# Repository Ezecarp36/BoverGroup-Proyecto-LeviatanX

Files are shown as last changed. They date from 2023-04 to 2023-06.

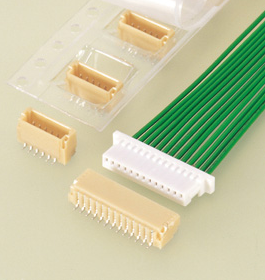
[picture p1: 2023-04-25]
Libreriaskicad(2023)/3d/3d/jst-sh-smd-connectors-1.snapshot.4/JST-SH-preview.png

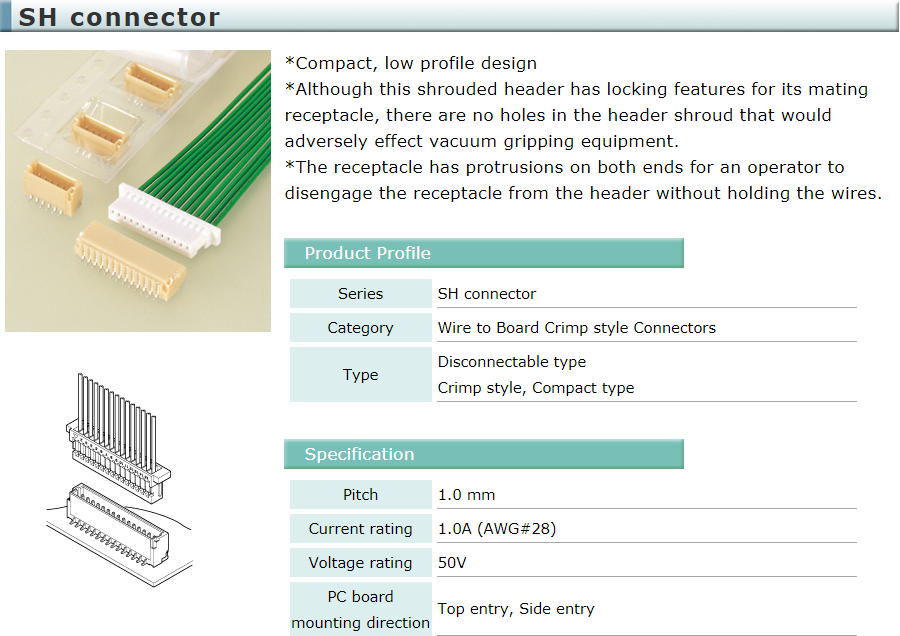
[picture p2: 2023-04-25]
Libreriaskicad(2023)/3d/3d/jst-sh-smd-connectors-1.snapshot.4/JST-SH.png

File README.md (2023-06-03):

# BoverGroup-Proyecto-LeviatanX
El Bover Group, compuesto por tres estudiantes de Septimo año de la E.E.S.T.Nº5 "2 DE ABRIL", se encuentra desarrollando un emocionante proyecto "LeviatanX" se trata en principio de un proyecto de varias etapas la primera es la realizacion de un drone controlado por radiocontrol para su uso en monitoreo y vigilancia. El proyecto será presentado en la materia Proyectos Electrónicos, dirigida por el Ing. Martin Leguizamón. Los integrantes del grupo son Leandro Benitez, Ezequiel Sierra y Gabriel Romero, quienes trabajan juntos para en un futuro automatizar el drone, permitiéndole volar de manera autónoma y a esto agregar la utilizacion de una cámara para reconocimiento con machine learning en tareas de monitoreo y vigilancia. Este proyecto tiene como objetivo ser un gran avance en la tecnología de drones, demostrando su creatividad y trabajo en equipo.
Tenemos un drive el cual plasmamos la informacion de los componentes usados y la documentacion necesaria para llevar a cabo el proyecto:
Drive: https://drive.google.com/drive/folders/1-x7SCu_ywuLYVk6GRU4Gz9AUGYImAjfw?usp=drive_link

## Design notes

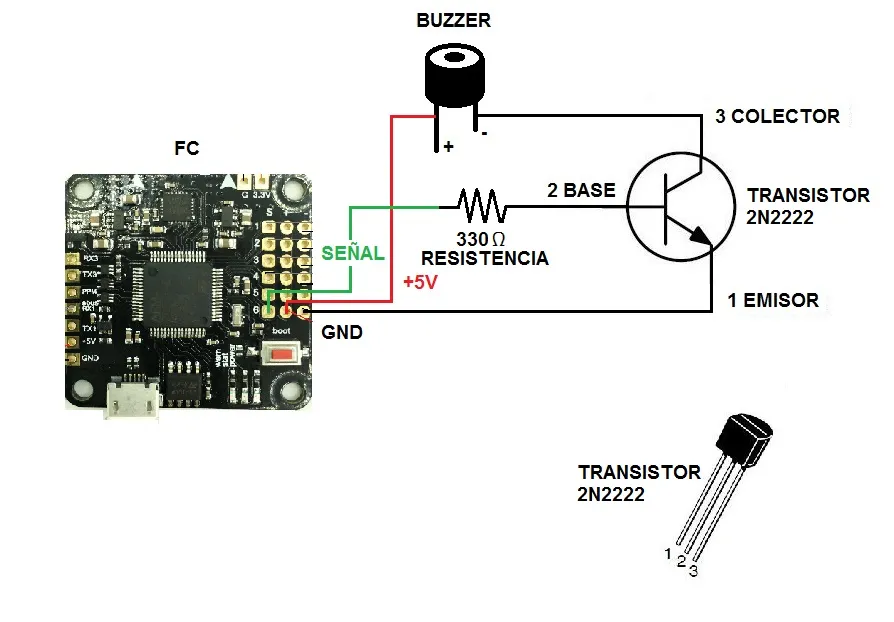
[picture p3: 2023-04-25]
Hardware/PCB-Controladora-Vuelo/Img/TransistorBuzzer.webp

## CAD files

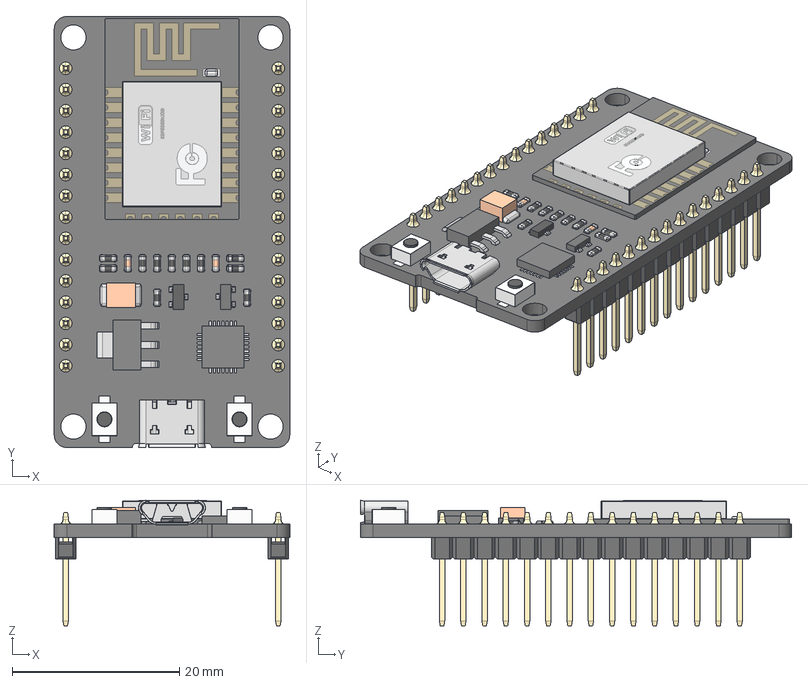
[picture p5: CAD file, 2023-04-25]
Libreriaskicad(2023)/3d/3d/esp32_dev_kit_v1_asm.stp
28.1 x 51.5 x 15.0 mm
PCB
PIN x 30
WIFI_CARD_2
RECTANGULARCHIP_2
MICROCHIP_2
TANCHIP_2
TRANSISTOR_3-LEG_2
RESISTOR1_2 x 11
RESISTOR2-32_2 x 2
TRANSISTOR_3-LEG2_2
BUTTONFLASH-13_2 x 2
BUTTONFLASH-14_2 x 2
USB_SOCKET_2

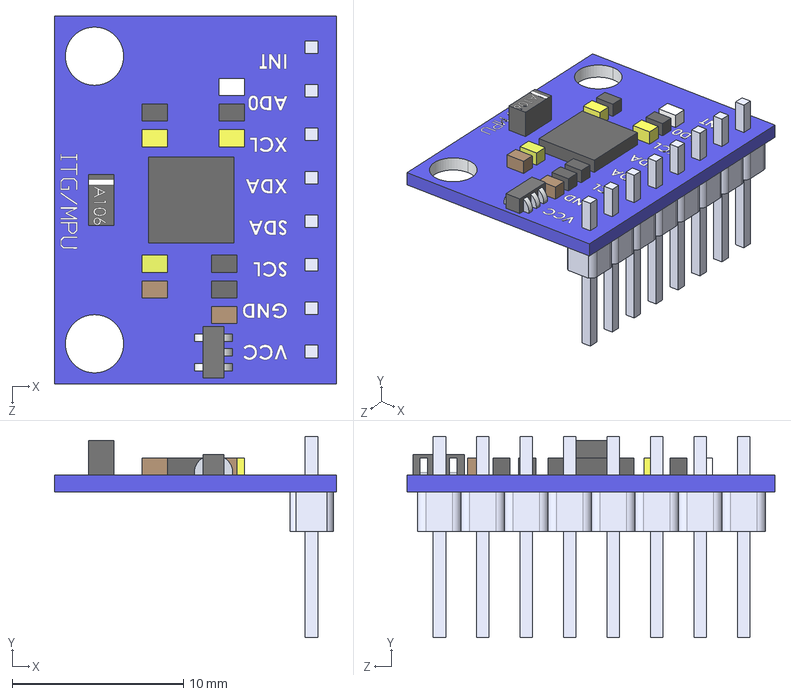
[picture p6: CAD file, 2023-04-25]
Libreriaskicad(2023)/3d/3d/ITG-MPU.STEP
16.5 x 11.8 x 21.5 mm
8 Header-Pin
Placa_Base

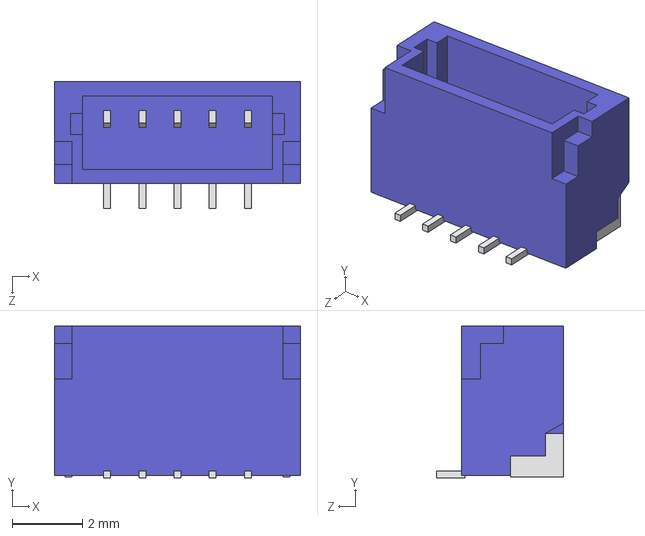
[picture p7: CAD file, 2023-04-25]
Libreriaskicad(2023)/3d/3d/jst-sh-smd-connectors-1.snapshot.4/BMxxB-SRSR-TB/BM05B-SRSS-TB.STEP
7.00 x 4.32 x 3.60 mm

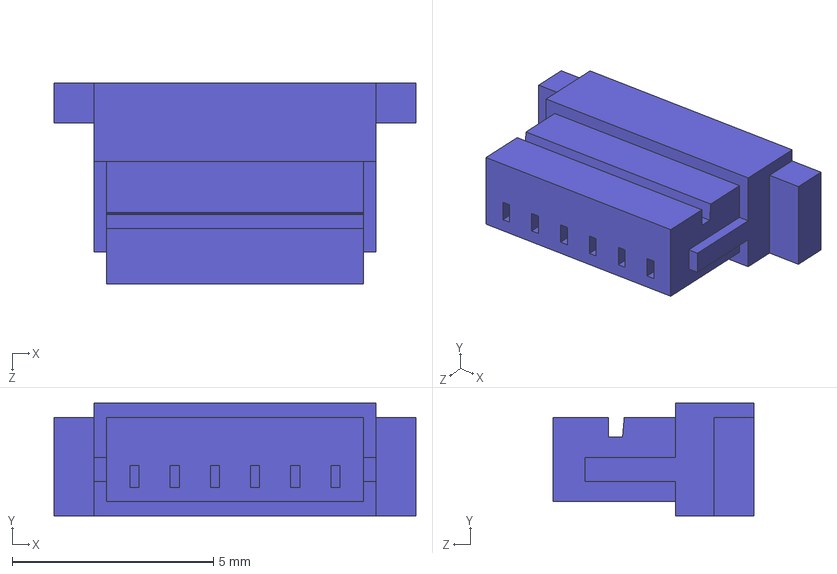
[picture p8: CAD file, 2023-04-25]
Libreriaskicad(2023)/3d/3d/jst-sh-smd-connectors-1.snapshot.4/SHR-xxV-S-B/SHR-06V-S-B.STEP
9.00 x 2.80 x 5.00 mm

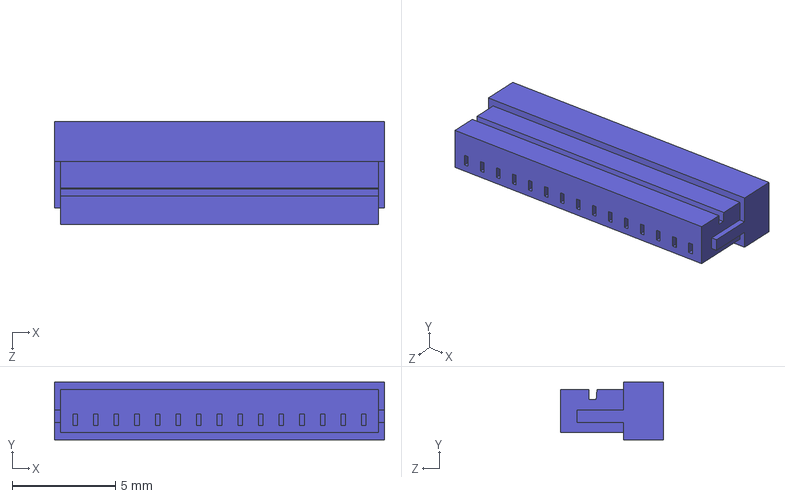
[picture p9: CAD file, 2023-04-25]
Libreriaskicad(2023)/3d/3d/jst-sh-smd-connectors-1.snapshot.4/SHR-xxV-S/SHR-15V-S.STEP
16.0 x 2.80 x 5.00 mm

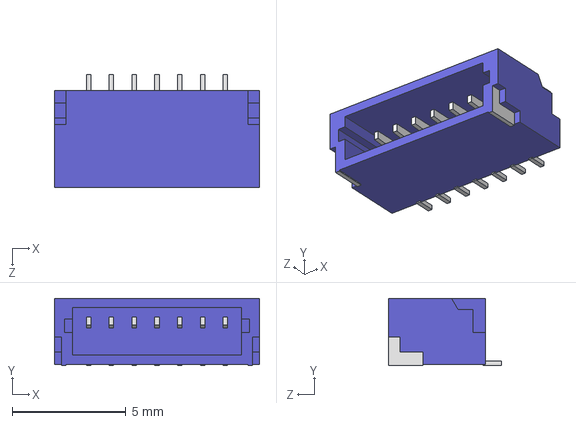
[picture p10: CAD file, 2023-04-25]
Libreriaskicad(2023)/3d/3d/jst-sh-smd-connectors-1.snapshot.4/SMxxB-SRSS-TB/SM07B-SRSS-TB.STEP
9.00 x 2.96 x 4.95 mm

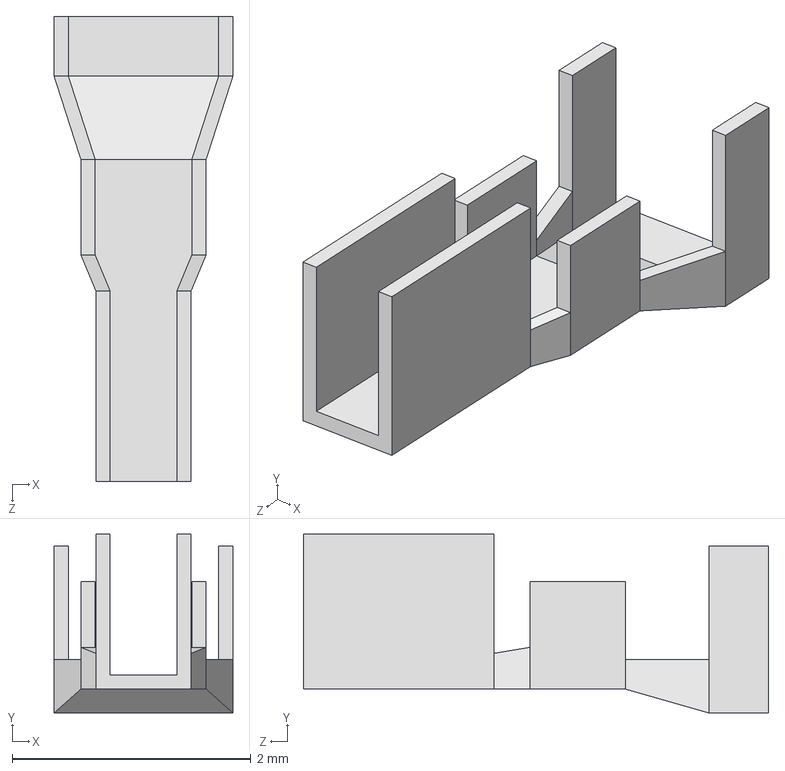
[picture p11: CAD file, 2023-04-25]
Libreriaskicad(2023)/3d/3d/jst-sh-smd-connectors-1.snapshot.4/SSH-003T-P0.2-H/SSH-003T-P0.2-H.STEP
1.50 x 1.50 x 3.90 mm

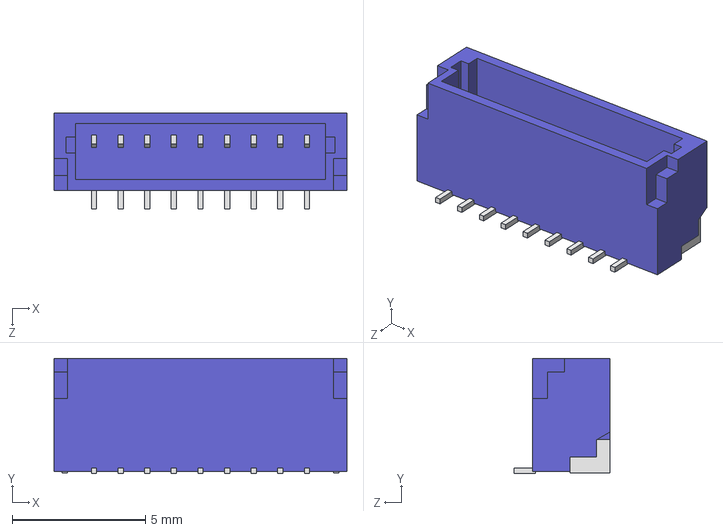
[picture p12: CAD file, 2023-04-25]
Libreriaskicad(2023)/3d/3d/jst-sh-smd-connectors-1.snapshot.4/BMxxB-SRSR-TB/BM09B-SRSS-TB.STEP
11.0 x 4.32 x 3.60 mm

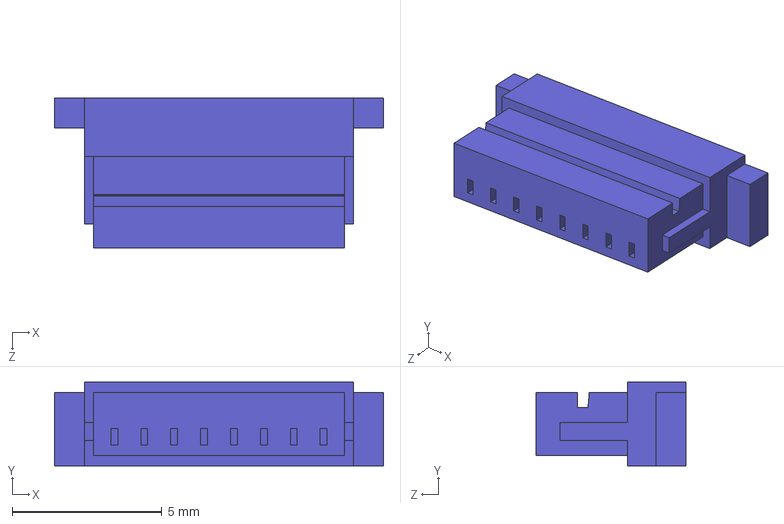
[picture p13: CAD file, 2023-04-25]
Libreriaskicad(2023)/3d/3d/jst-sh-smd-connectors-1.snapshot.4/SHR-xxV-S-B/SHR-08V-S-B.STEP
11.0 x 2.80 x 5.00 mm

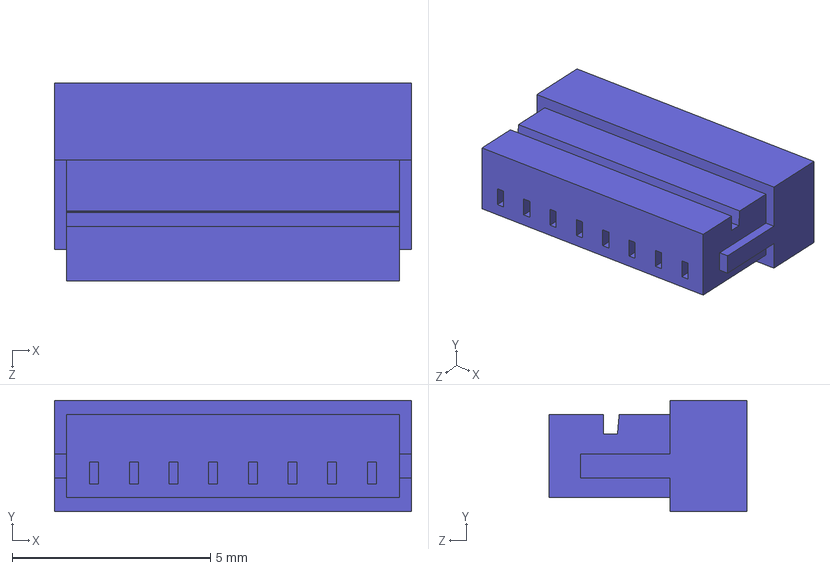
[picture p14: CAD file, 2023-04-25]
Libreriaskicad(2023)/3d/3d/jst-sh-smd-connectors-1.snapshot.4/SHR-xxV-S/SHR-08V-S.STEP
9.00 x 2.80 x 5.00 mm

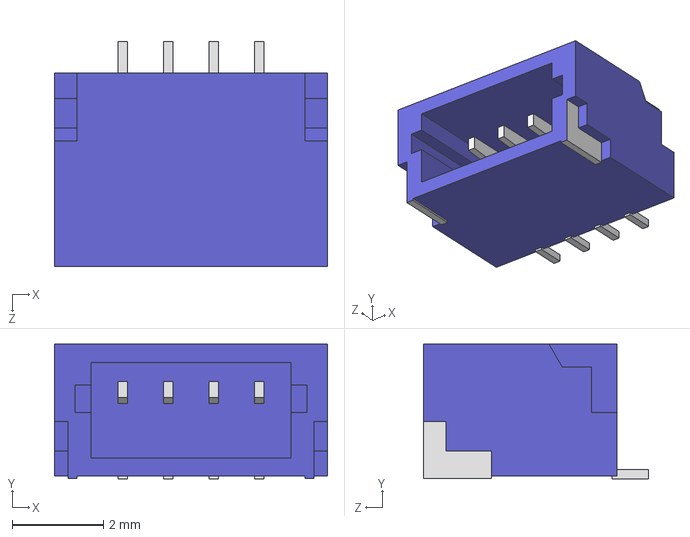
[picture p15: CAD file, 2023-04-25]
Libreriaskicad(2023)/3d/3d/jst-sh-smd-connectors-1.snapshot.4/SMxxB-SRSS-TB/SM04B-SRSS-TB.STEP
6.00 x 2.96 x 4.95 mm

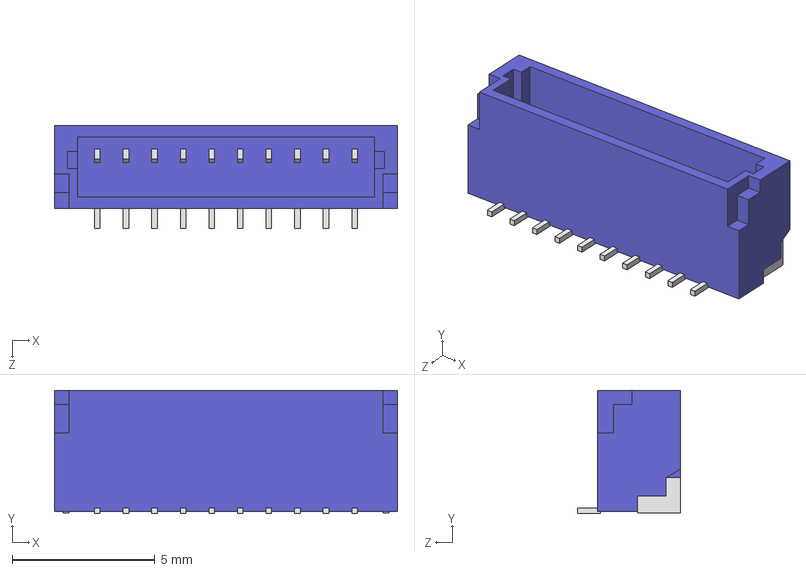
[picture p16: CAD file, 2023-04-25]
Libreriaskicad(2023)/3d/3d/jst-sh-smd-connectors-1.snapshot.4/BMxxB-SRSR-TB/BM10B-SRSS-TB.STEP
12.0 x 4.32 x 3.60 mm

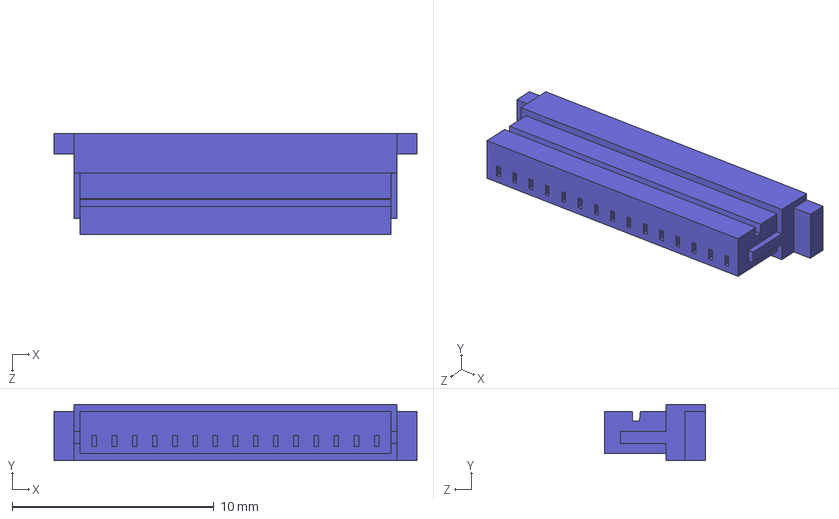
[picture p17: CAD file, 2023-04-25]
Libreriaskicad(2023)/3d/3d/jst-sh-smd-connectors-1.snapshot.4/SHR-xxV-S-B/SHR-15V-S-B.STEP
18.0 x 2.80 x 5.00 mm

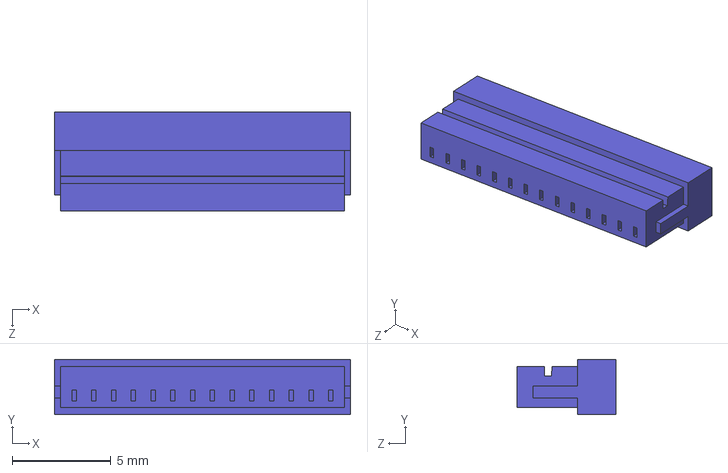
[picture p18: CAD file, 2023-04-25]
Libreriaskicad(2023)/3d/3d/jst-sh-smd-connectors-1.snapshot.4/SHR-xxV-S/SHR-14V-S.STEP
15.0 x 2.80 x 5.00 mm

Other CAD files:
Libreriaskicad(2023)/3d/3d/jst-sh-smd-connectors-1.snapshot.4/SMxxB-SRSS-TB/SM02B-SRSS-TB.STEP
Libreriaskicad(2023)/3d/3d/NRF24L01.step
Libreriaskicad(2023)/3d/3d/jst-sh-smd-connectors-1.snapshot.4/BMxxB-SRSR-TB/BM06B-SRSS-TB.STEP
Libreriaskicad(2023)/3d/3d/jst-sh-smd-connectors-1.snapshot.4/SHR-xxV-S-B/SHR-09V-S-B.STEP
Libreriaskicad(2023)/3d/3d/jst-sh-smd-connectors-1.snapshot.4/BMxxB-SRSR-TB/BM02B-SRSS-TB.STEP
Libreriaskicad(2023)/3d/3d/jst-sh-smd-connectors-1.snapshot.4/BMxxB-SRSR-TB/BM03B-SRSS-TB.STEP
Libreriaskicad(2023)/3d/3d/jst-sh-smd-connectors-1.snapshot.4/BMxxB-SRSR-TB/BM04B-SRSS-TB.STEP
Libreriaskicad(2023)/3d/3d/jst-sh-smd-connectors-1.snapshot.4/BMxxB-SRSR-TB/BM07B-SRSS-TB.STEP
Libreriaskicad(2023)/3d/3d/jst-sh-smd-connectors-1.snapshot.4/BMxxB-SRSR-TB/BM08B-SRSS-TB.STEP
Libreriaskicad(2023)/3d/3d/jst-sh-smd-connectors-1.snapshot.4/BMxxB-SRSR-TB/BM11B-SRSS-TB.STEP
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

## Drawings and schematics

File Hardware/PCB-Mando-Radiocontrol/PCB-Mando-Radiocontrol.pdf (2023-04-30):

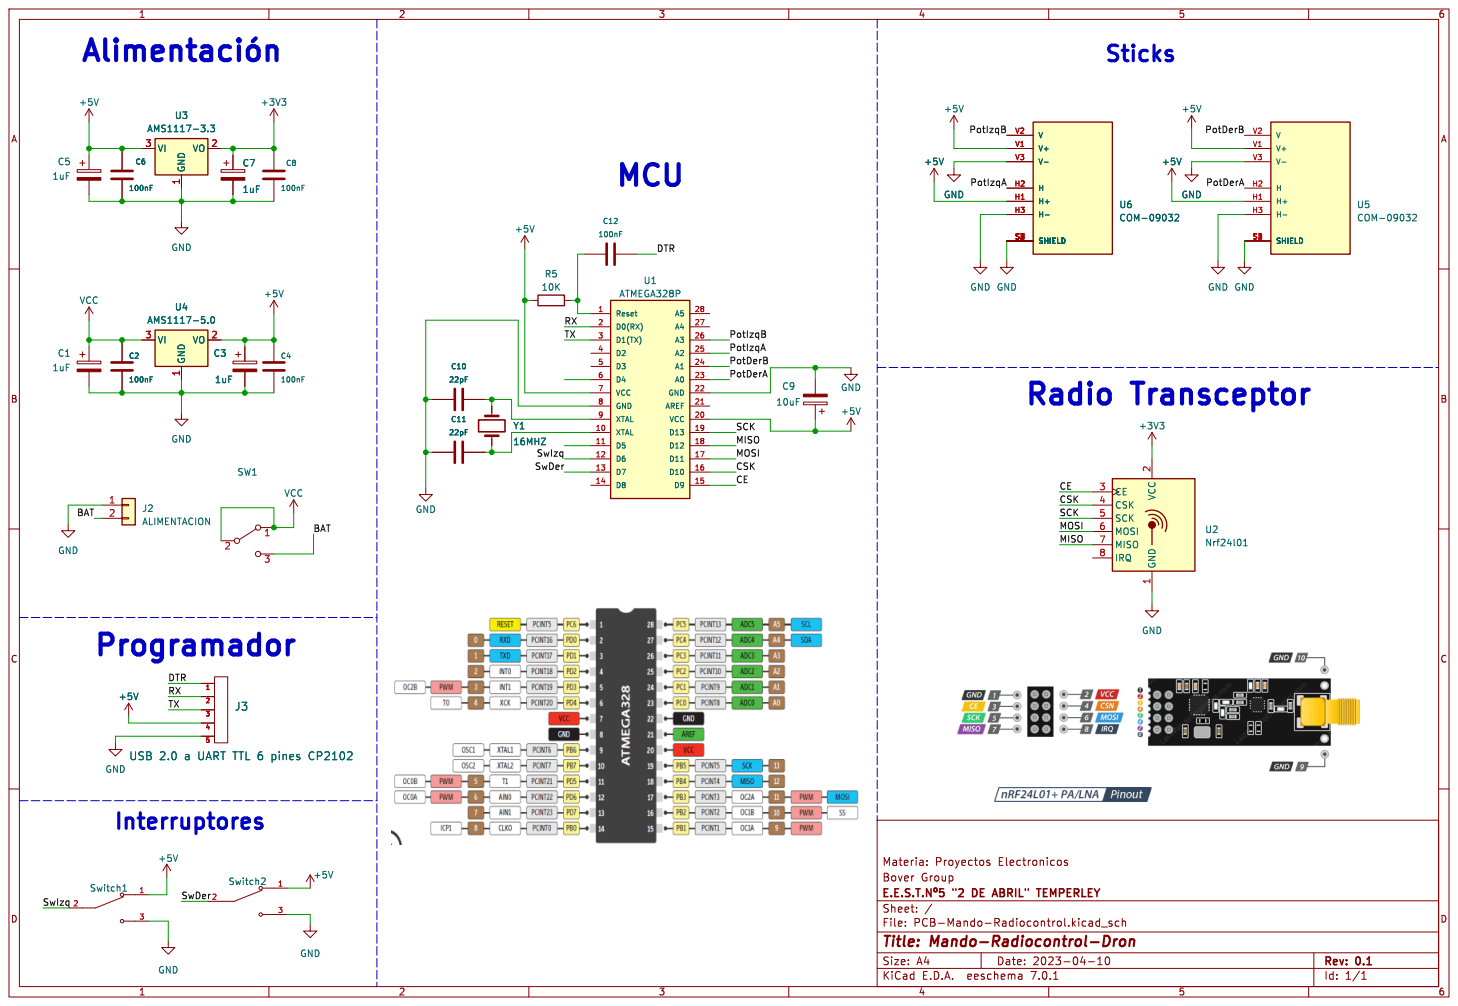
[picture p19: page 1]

1 VO 2 VI 3 U4 AMS1117-5.0 VCC GND

2 CE 3 CSK 4 SCK 5 MOSI 6 MISO 7

J3 USB 2.0 a UART TTL 6 pines CP2102

Id: 1/1 Title: Mando-Radiocontrol-Dron

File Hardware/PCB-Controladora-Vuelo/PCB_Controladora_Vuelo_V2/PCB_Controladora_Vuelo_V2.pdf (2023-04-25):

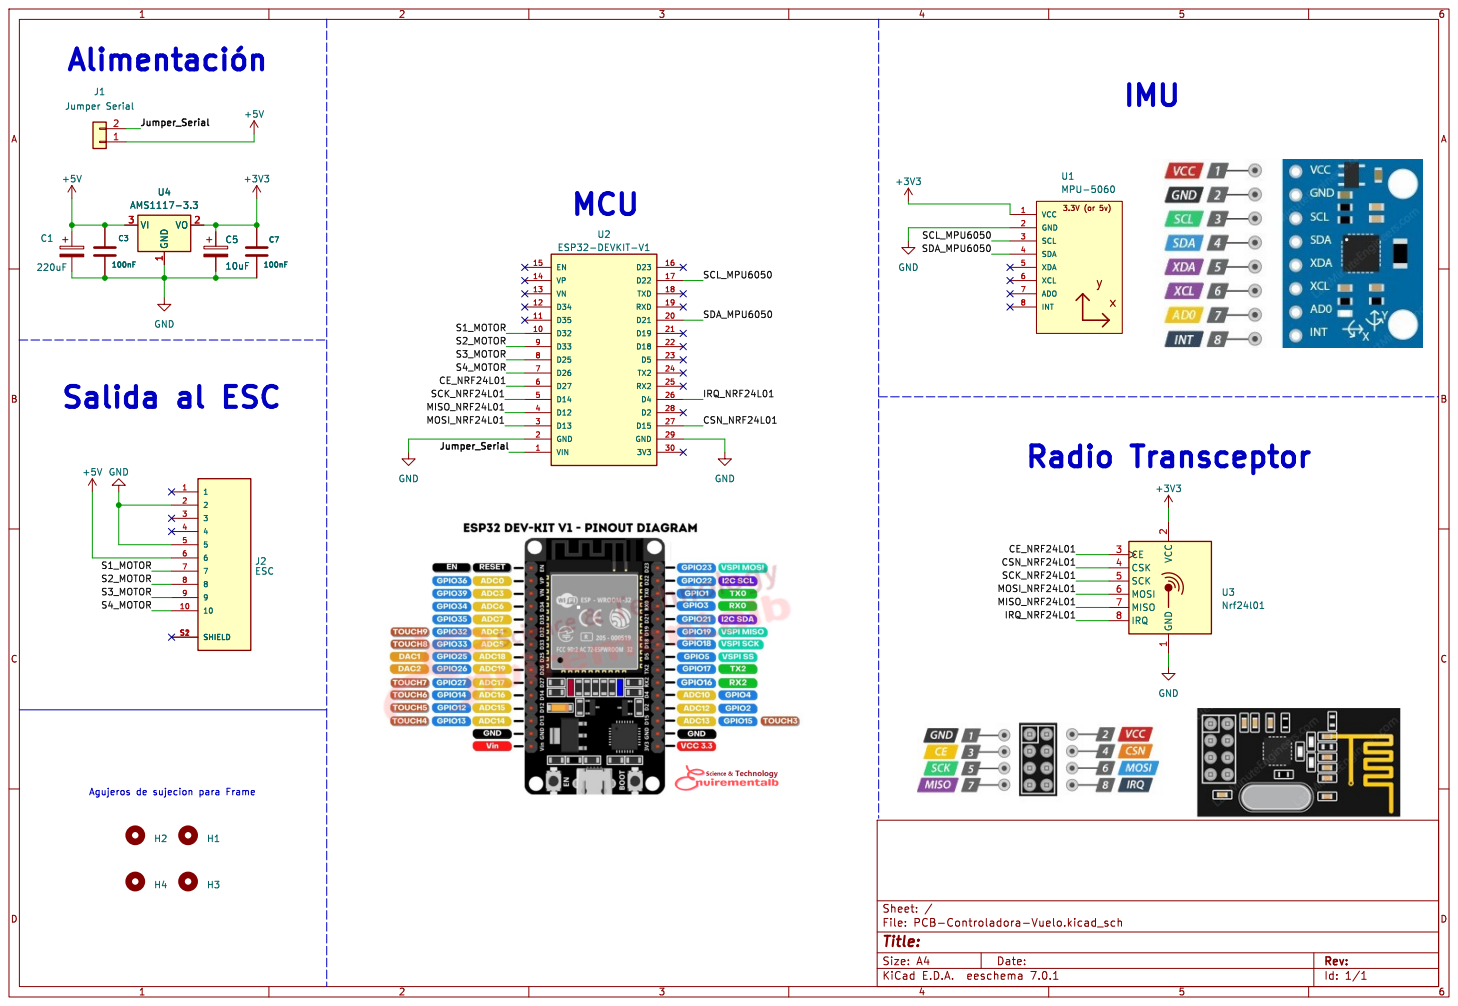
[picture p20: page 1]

1 VO 2 VI 3 U4 AMS1117-3.3 GND GND

2 CE 3 CSK 4 SCK 5 MOSI 6 MISO 7

Agujeros de sujecion para Frame

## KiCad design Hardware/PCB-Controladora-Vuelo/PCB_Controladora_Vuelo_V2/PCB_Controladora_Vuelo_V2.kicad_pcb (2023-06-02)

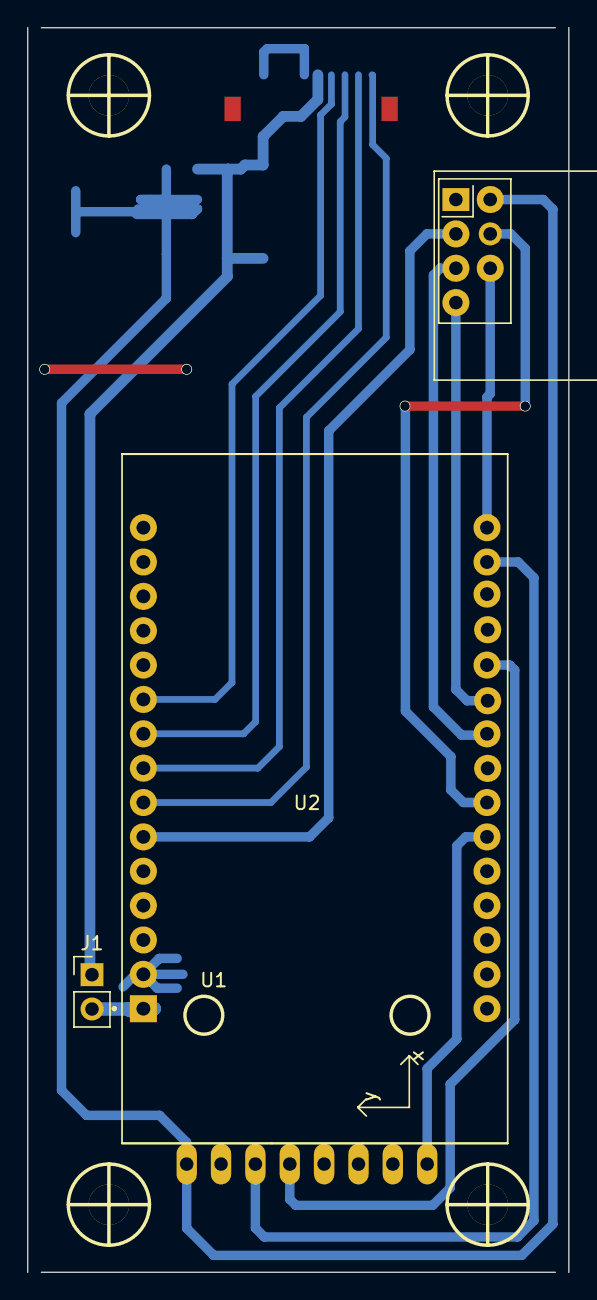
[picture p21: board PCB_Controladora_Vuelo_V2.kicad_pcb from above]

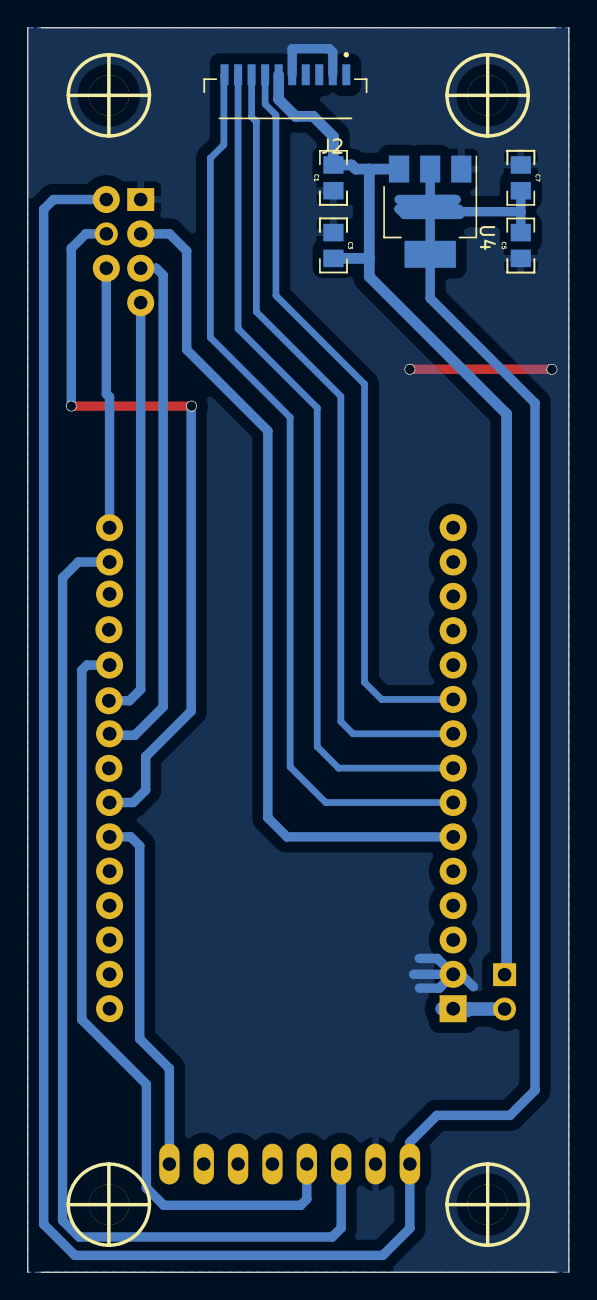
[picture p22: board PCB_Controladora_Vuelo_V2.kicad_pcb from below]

Board: 2 copper layers, 40.0 x 92.0 mm, 14 parts (6 on the bottom side), 16 nets.

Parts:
C1, C5: 10uF; C_0805
C3, C7: 100nF; C_0805
H1, H2, H3, H4: Mounting_Hole; hole_3mm
J1: Jumper Serial; PinHeader_1x02_P2.54mm_Vertical
J2: ESC; JST10mm
U1: MPU-5060; MPU-6050
U2: ESP32-DEVKIT-V1; ESP32-DEVKIT-V1-30Pines
U3: Nrf24l01; nRF24L01_Breakout
U4: AMS1117-3.3; SOT-223-3_TabPin2

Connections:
+3V3: C5.1, C7.1, U1.1 (VCC), U3.2 (VCC), U4.2 (VO)
+5V: C1.1, C3.1, J1.1, J2.6, U4.3 (VI)
/CE_NRF24L01: U2.6 (D27), U3.3 (CE)
/CSN_NRF24L01: U2.24 (TX2), U3.4 (CSK)
/INT_MPU6050: U1.8 (INT), U2.25 (RX2)
/Jumper_Serial: J1.2, U2.1 (VIN)
/MISO_NRF24L01: U2.21 (D19), U3.7 (MISO)
/MOSI_NRF24L01: U2.16 (D23), U3.6 (MOSI)
/S1_MOTOR: J2.7, U2.10 (D32)
/S2_MOTOR: J2.8, U2.9 (D33)
/S3_MOTOR: J2.9, U2.8 (D25)
/S4_MOTOR: J2.10, U2.7 (D26)
/SCK_NRF24L01: U2.22 (D18), U3.5 (SCK)
/SCL_MPU6050: U1.3 (SCL), U2.17 (D22)
/SDA_MPU6050: U1.4 (SDA), U2.20 (D21)
GND: C1.2, C3.2, C5.2, C7.2, J2.2, J2.5, U1.2 (GND), U2.2 (GND), U2.29 (GND), U3.1 (GND), U4.1 (GND)

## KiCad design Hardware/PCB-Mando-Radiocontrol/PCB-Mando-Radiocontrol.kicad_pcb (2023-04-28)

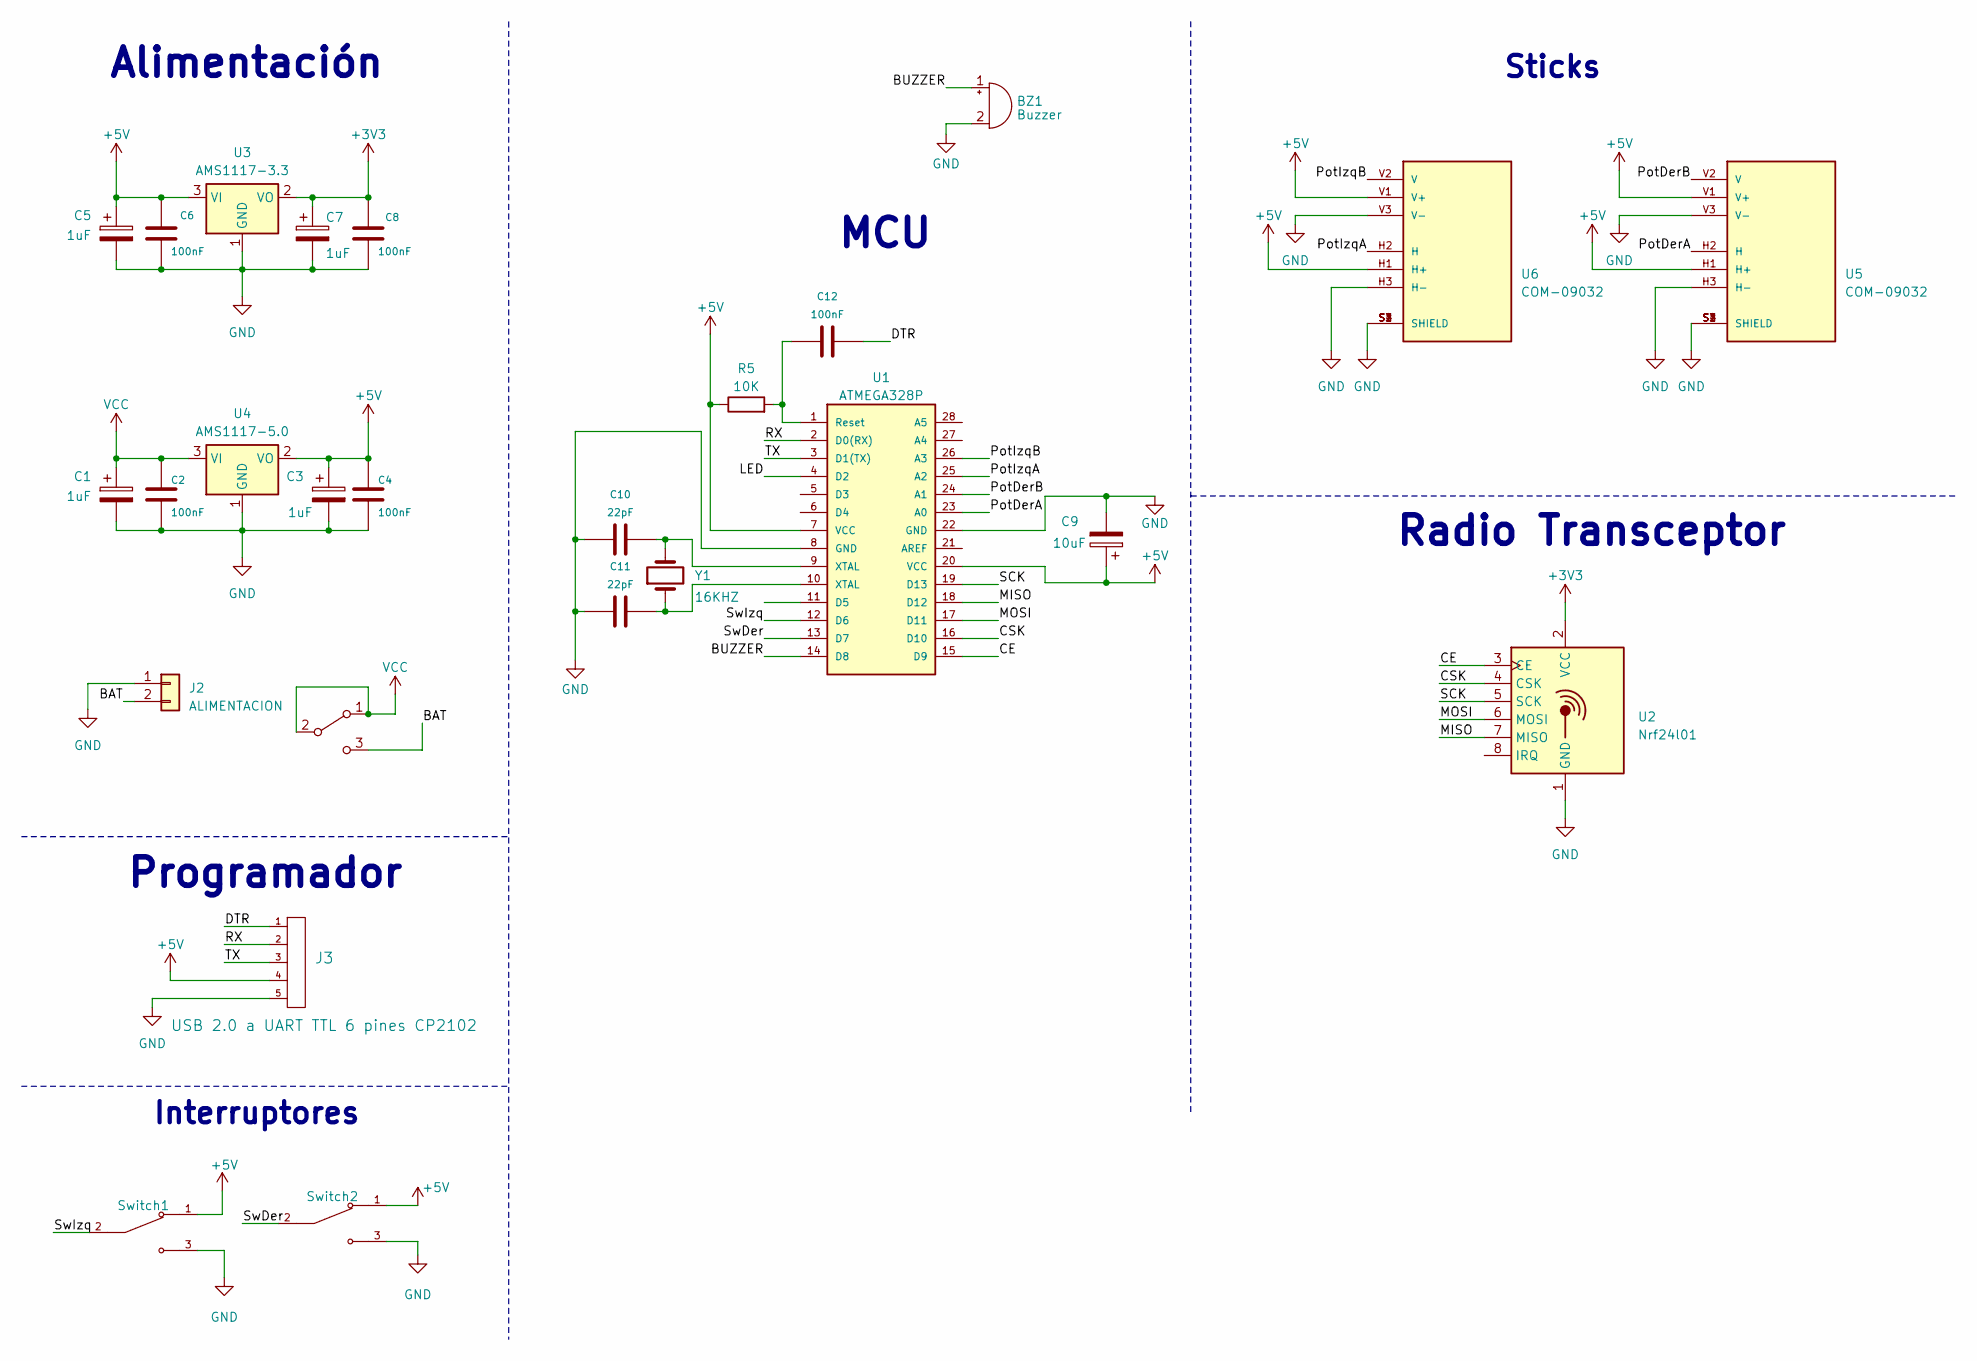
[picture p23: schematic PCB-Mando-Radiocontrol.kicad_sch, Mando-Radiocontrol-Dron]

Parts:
BZ1: Buzzer; Buzzer_12mm
C1, C3, C5, C7: 1uF; CAP_ELEC_5x11mm
C2, C4, C6, C8, C12: 100nF; C_1206_3216Metric
C9: 10uF; CAP_ELEC_5x11mm
C10, C11: 22pF; C_1206_3216Metric
J2: ALIMENTACION; JST_PH_B2B-PH-K_1x02_P2.00mm_Vertical
J3: USB 2.0 a UART TTL 6 pines CP2102; Pin_Header_5
R5: 10K; R_1206_3216Metric
SW1: SW_100SP3T1B1M2QE
Switch1, Switch2: SW_100SP3T1B1M2QE; PARTREV B
U1: ATMEGA328P; DIP_28-300_socket
U2: Nrf24l01; nRF24L01_Breakout
U3: AMS1117-3.3; SOT-223-3_TabPin2
U4: AMS1117-5.0; SOT-223-3_TabPin2
U5, U6: COM-09032; XDCR_COM-09032; PARTREV N/A
Y1: 16KHZ; XTAL_XT9S20ANA16M

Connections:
+3V3: C7.1, C8.1, U2.2 (VCC), U3.2 (VO)
+5V: C3.1, C4.1, C5.1, C6.1, C9.1, J3.4, R5.1, Switch1.1, Switch2.1, U1.7 (VCC), U1.20 (VCC), U3.3 (VI), U4.2 (VO), U5.H1 (H+), U5.V1 (V+), U6.H1 (H+), U6.V1 (V+)
/BAT: J2.2, SW1.3 (C)
/BUZZER: BZ1.1 (-), U1.14 (D8)
/CE: U1.15 (D9), U2.3 (CE)
/CSK: U1.16 (D10), U2.4 (CSK)
/DTR: C12.2, J3.1
/LED: U1.4 (D2)
/MISO: U1.18 (D12), U2.7 (MISO)
/MOSI: U1.17 (D11), U2.6 (MOSI)
/PotDerA: U1.23 (A0), U5.H2 (H)
/PotDerB: U1.24 (A1), U5.V2 (V)
/PotIzqA: U1.25 (A2), U6.H2 (H)
/PotIzqB: U1.26 (A3), U6.V2 (V)
/RX: J3.2, U1.2 (D0(RX))
/SCK: U1.19 (D13), U2.5 (SCK)
/SwDer: Switch2.2, U1.13 (D7)
/SwIzq: Switch1.2, U1.12 (D6)
/TX: J3.3, U1.3 (D1(TX))
GND: BZ1.2 (+), C1.2, C2.2, C3.2, C4.2, C5.2, C6.2, C7.2, C8.2, C9.2, C10.1, C11.1, J2.1, J3.5, Switch1.3, Switch2.3, U1.8 (GND), U1.22 (GND), U2.1 (GND), U3.1 (GND), U4.1 (GND), U5.H3 (H-), U5.S1 (SHIELD), U5.S2 (SHIELD), U5.S3 (SHIELD), U5.S4 (SHIELD), U5.V3 (V-), U6.H3 (H-), U6.S1 (SHIELD), U6.S2 (SHIELD), U6.S3 (SHIELD), U6.S4 (SHIELD), U6.V3 (V-)
unnamed: C10.2, U1.9 (XTAL), Y1.2
unnamed: C11.2, U1.10 (XTAL), Y1.1
unnamed: C12.1, R5.2, U1.1 (Reset)
VCC: C1.1, C2.1, SW1.1 (A), SW1.2 (B), U4.3 (VI)

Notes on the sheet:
Radio Transceptor
Alimentación
MCU
Programador
Interruptores
Sticks

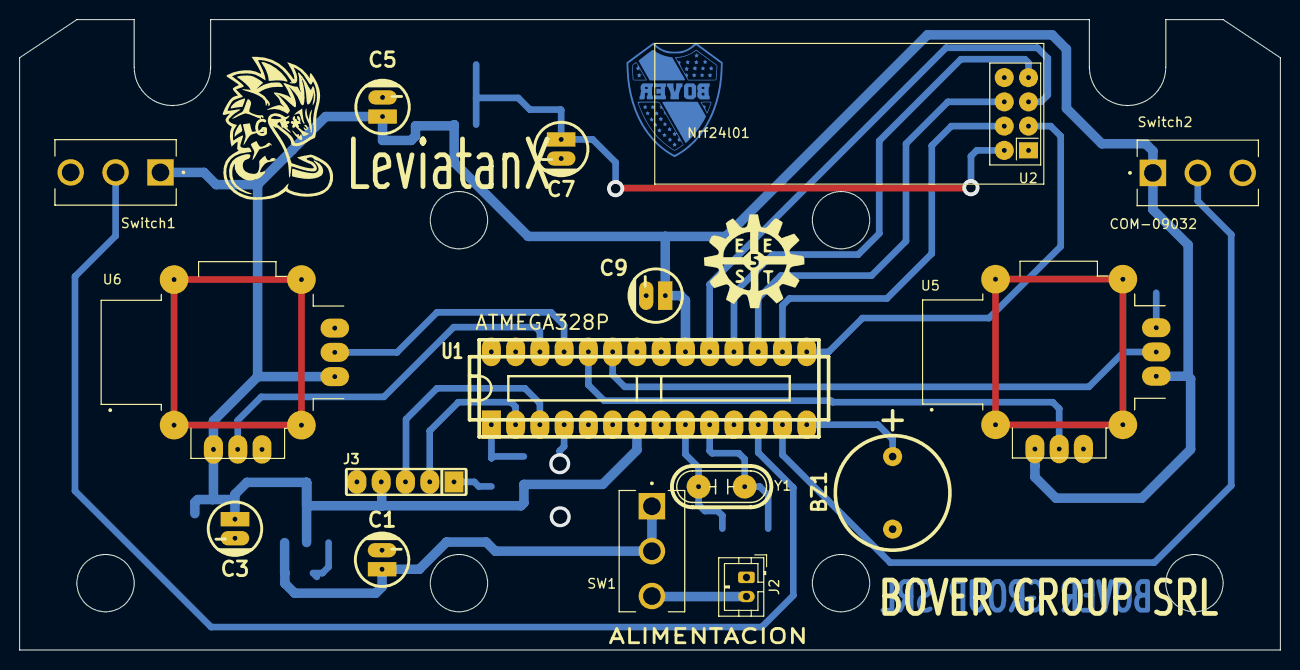
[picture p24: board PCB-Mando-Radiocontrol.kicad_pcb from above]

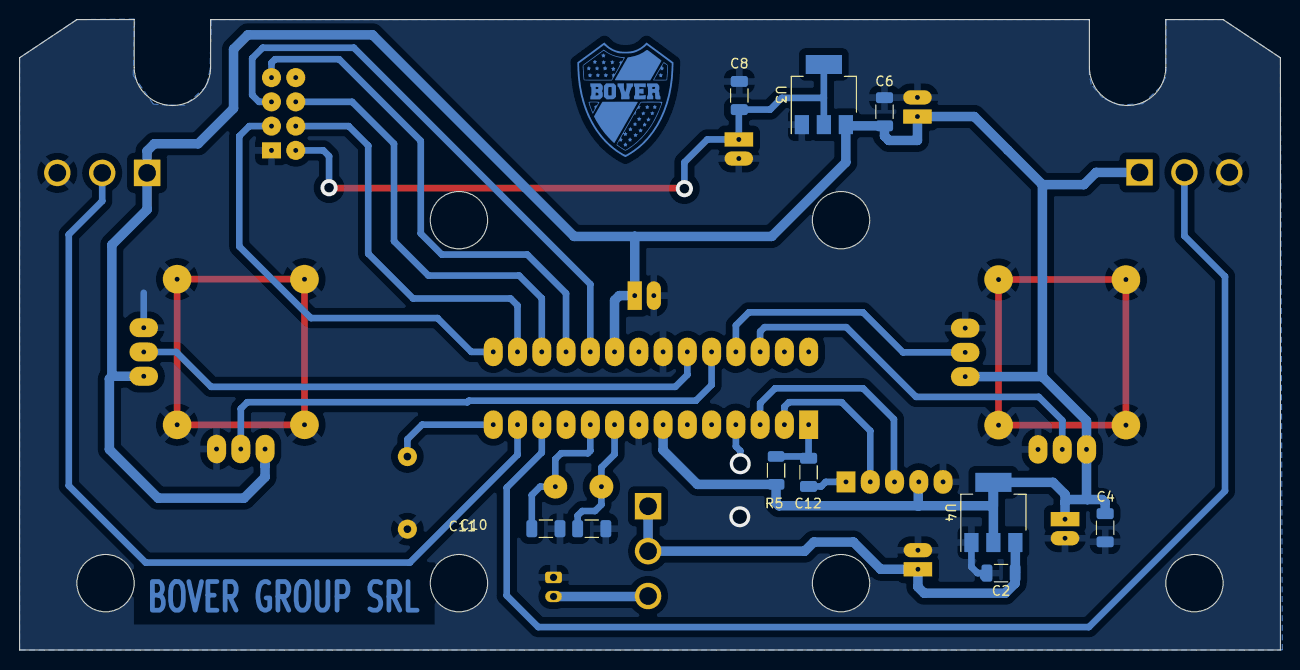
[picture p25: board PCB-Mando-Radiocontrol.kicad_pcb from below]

Board: 2 copper layers, 132.0 x 66.0 mm, 26 parts (10 on the bottom side), 23 nets.

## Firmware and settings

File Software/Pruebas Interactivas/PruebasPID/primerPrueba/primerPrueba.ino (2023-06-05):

#include "PID.h"
#include "I2Cdev.h"
#include "MPU6050_6Axis_MotionApps20.h"
#include <RF24.h>
#include <ESP32Servo.h>
#include "BluetoothSerialBT.h"
#if I2CDEV_IMPLEMENTATION == I2CDEV_ARDUINO_WIRE
#include "Wire.h"
#endif

#if !defined(CONFIG_BT_ENABLED) || !defined(CONFIG_BLUEDROID_ENABLED)
#error Bluetooth is not enabled! Please run `make menuconfig` to and enable it
#endif

// constantes
#define PIN_MOTOR_1 32
#define PIN_MOTOR_2 33
#define PIN_MOTOR_3 25
#define PIN_MOTOR_4 26
#define PIN_INTERRUPT 16
#define PIN_CE 27
#define PIN_CSN 17
#define TICK_DEBUG 100
#define VELOCIDAD_ESCALADA 3
#define VELOCIDAD_MAXIMA 1800
#define TICK_PID_PITCH 10
#define NIVEL_MOTOR_PARADO 0
#define NIVEL_MOTOR_BAJO 1200
#define NIVEL_MOTOR_MEDIOBAJO 1400
#define NIVEL_MOTOR_MEDIOALTO 1600
#define NIVEL_MOTOR_ALTO 1800
#define CALIBRACION_XGYROOFFSET 220
#define CALIBRACION_YGYROOFFSET 76
#define CALIBRACION_ZGYROOFFSET -85
#define CALIBRACION_ZACCELOFFSET 1688

// variables
double input = 0.0;
double setpoint_pitch = 0.0;
double kp_pitch = 0.2, ti_pitch = 0.2, td_pitch = 0.2;
int pitch, yaw, roll;
int velocidad_pitch = 0;
bool estado_boton = false;
int velocidad_pitch_aumenta, velocidad_pitch_disminuye;
int resultadoPidPitch;

enum state
{
    ESPERA,
    INICIO_DE_VUELO,
    PRUEBA_PID
};
int state = ESPERA;

// inicializo objetos
RF24 radio(PIN_CE, PIN_CSN);
BluetoothSerial SerialBT;
MPU6050 mpu;
Pid *calculo_pid_pitch = new Pid(kp_pitch, ti_pitch, td_pitch, setpoint_pitch, TICK_PID_PITCH);
Servo motor1;
Servo motor2;
Servo motor3;
Servo motor4;

// Variables de estado y control MPU
bool dmpReady = false;  // set true if DMP init was successful
uint8_t mpuIntStatus;   // holds actual interrupt status byte from MPU
uint8_t devStatus;      // return status after each device operation (0 = success, !0 = error)
uint16_t packetSize;    // expected DMP packet size (default is 42 bytes)
uint16_t fifoCount;     // count of all bytes currently in FIFO
uint8_t fifoBuffer[64]; // FIFO storage buffer
Quaternion q;           // [w, x, y, z]
VectorInt16 aa;         // [x, y, z]
VectorInt16 aaReal;     // [x, y, z]
VectorInt16 aaWorld;    // [x, y, z]
VectorFloat gravity;    // [x, y, z]
float ypr[3];           // [yaw, pitch, roll]

// FUNCION QUE CAMBIA A ALTO CUANDO INT RECIBE DATOS DE LA MPU E INTERRUMPE uC
volatile bool mpuInterrupt = false;
void dmpDataReady()
{
    mpuInterrupt = true;
}

void setup()
{
    // inicializar I2C con MPU6050 en biblioteca I2Cdev se utiliza la biblioteca Wire o Fastwire para establecer la comunicación y configurar la frecuencia de reloj del bus I2C.
#if I2CDEV_IMPLEMENTATION == I2CDEV_ARDUINO_WIRE
    Wire.begin();
    Wire.setClock(400000); // 400kHz I2C clock. Comment this line if having compilation difficulties
#elif I2CDEV_IMPLEMENTATION == I2CDEV_BUILTIN_FASTWIRE
    Fastwire::setup(400, true);
#endif
    // configuracion comunicacion a rf del receptor
    radio.begin();
    radio.setDataRate(RF24_250KBPS);
    radio.openReadingPipe(1, ADDRESS);
    radio.startListening();
    Serial.begin(9600);

    // nombre bluetooth y mensaje
    SerialBT.begin("LeviatanX"); // Bluetooth device name
    SerialBT.println("Start Bluetooth");
    delay(3000);
    // Iniciar MPU6050
    SerialBT.println(F("Initializing I2C devices..."));
    mpu.initialize();
    // configuramos motores
    motor1.attach(PIN_MOTOR_1); // Inicializa el motor brushless en el pin correspondiente
    motor2.attach(PIN_MOTOR_2);
    motor3.attach(PIN_MOTOR_3);
    motor4.attach(PIN_MOTOR_4);
    pinMode(PIN_INTERRUPT, INPUT);
    // Comprobar  conexion
    SerialBT.println(F("Testing device connections..."));
    SerialBT.println(mpu.testConnection() ? F("MPU6050 connection successful") : F("MPU6050 connection failed"));
    // Iniciar DMP
    SerialBT.println(F("Initializing DMP..."));
    devStatus = mpu.dmpInitialize();
    // Valores de calibracion
    mpu.setXGyroOffset(CALIBRACION_XGYROOFFSET);
    mpu.setYGyroOffset(CALIBRACION_YGYROOFFSET);
    mpu.setZGyroOffset(CALIBRACION_ZGYROOFFSET);
    mpu.setZAccelOffset(CALIBRACION_ZACCELOFFSET);
    // Activar DMP
    if (devStatus == 0)
    {
        SerialBT.println(F("Enabling DMP..."));
        mpu.setDMPEnabled(true);
        // Activar interrupcion
        attachInterrupt(digitalPinToInterrupt(PIN_INTERRUPT), dmpDataReady, RISING);
        mpuIntStatus = mpu.getIntStatus();
        SerialBT.println(F("DMP ready! Waiting for first interrupt..."));
        dmpReady = true;
        // get expected DMP packet size for later comparison
        packetSize = mpu.dmpGetFIFOPacketSize();
    }
    else
    {
        // ERROR!
        // 1 = initial memory load failed
        // 2 = DMP configuration updates failed
        // (if it's going to break, usually the code will be 1)
        SerialBT.print(F("DMP Initialization failed (code "));
        SerialBT.print(devStatus);
        SerialBT.println(F(")"));
    }
}

void loop()
{
    // Si fallo al iniciar, parar programa
    if (!dmpReady)
        return;

    // Ejecutar mientras no hay interrupcion
    while (!mpuInterrupt && fifoCount < packetSize)
    {                          // AQUI EL RESTO DEL CODIGO DE TU PROGRRAMA
        if (radio.available()) // si hay comunicacion recibe mensaje
        {
            radio.read(&estado_boton, sizeof(estado_boton)); // recibe mensaje
            bool lectura_boton = digitalRead(estado_boton);
            resultadoPidPitch = calculo_pid_pitch->ComputePid(pitch);
            switch (state)
            {
            case ESPERA:
            {
                velocidad_pitch = NIVEL_MOTOR_PARADO;
                motor1.writeMicroseconds(velocidad_pitch);
                motor2.writeMicroseconds(velocidad_pitch);
                motor3.writeMicroseconds(velocidad_pitch);
                motor4.writeMicroseconds(velocidad_pitch);
                if (lectura_boton)
                {
                    state = INICIO_DE_VUELO;
                }
                break;
            }
            case INICIO_DE_VUELO:
            {   

                for (int i = 1000; i < 1800; i = i + 25)
                {
                    motor1.writeMicroseconds(i);
                    motor2.writeMicroseconds(i);
                    motor3.writeMicroseconds(i);
                    motor4.writeMicroseconds(i);
                    delay(500);
                    if (i >= 1400)
                    {
                        state = PRUEBA_PID;
                    }
                }
                if (lectura_boton == 0)
                {
                    state = ESPERA;
                }
                break;
            }
            case PRUEBA_PID:
            {
                if (pitch > setpoint_pitch)
                {
                    velocidad_pitch_aumenta = velocidad_pitch + resultadoPidPitch;
                    velocidad_pitch_disminuye = velocidad_pitch - resultadoPidPitch;
                    motor1.writeMicroseconds(velocidad_pitch_aumenta);
                    motor2.writeMicroseconds(velocidad_pitch_disminuye);
                    motor3.writeMicroseconds(velocidad_pitch_aumenta);
                    motor4.writeMicroseconds(velocidad_pitch_disminuye);
                }
                else if (pitch < setpoint_pitch)
                {
                    velocidad_pitch_aumenta = velocidad_pitch + resultadoPidPitch;
                    velocidad_pitch_disminuye = velocidad_pitch - resultadoPidPitch;
                    motor1.writeMicroseconds(velocidad_pitch_disminuye);
                    motor2.writeMicroseconds(velocidad_pitch_aumenta);
                    motor3.writeMicroseconds(velocidad_pitch_disminuye);
                    motor4.writeMicroseconds(velocidad_pitch_aumenta);
                }
                else
                {
                    velocidad_pitch = 1400;
                    motor1.writeMicroseconds(velocidad_pitch);
                    motor2.writeMicroseconds(velocidad_pitch);
                    motor3.writeMicroseconds(velocidad_pitch);
                    motor4.writeMicroseconds(velocidad_pitch);
                }
                if (lectura_boton == 0)
                {
                    state = ESPERA;
                }
                break;
            }
            }
        }
    }

    mpuInterrupt = false;
    mpuIntStatus = mpu.getIntStatus();

    // Obtener datos del FIFO
    fifoCount = mpu.getFIFOCount();

    // Controlar overflow
    if ((mpuIntStatus & 0x10) || fifoCount == 1024)
    {
        mpu.resetFIFO();
        SerialBT.println(F("FIFO overflow!"));
    }
    else if (mpuIntStatus & 0x02)
    {
        // wait for correct available data length, should be a VERY short wait
        while (fifoCount < packetSize)
            fifoCount = mpu.getFIFOCount();

        // read a packet from FIFO
        mpu.getFIFOBytes(fifoBuffer, packetSize);

        // track FIFO count here in case there is > 1 packet available
        // (this lets us immediately read more without waiting for an interrupt)
        fifoCount -= packetSize;

        // MMostrar Yaw, Pitch, Roll
        mpu.dmpGetQuaternion(&q, fifoBuffer);
        mpu.dmpGetGravity(&gravity, &q);
        mpu.dmpGetYawPitchRoll(ypr, &q, &gravity);
        yaw = ypr[0] * 180 / M_PI;
        pitch = ypr[1] * 180 / M_PI;
        roll = ypr[2] * 180 / M_PI;
        SerialBT.print("ypr\t");
        SerialBT.print(yaw);
        SerialBT.print("\t");
        SerialBT.print(pitch);
        SerialBT.print("\t");
        SerialBT.println(roll);

        delay(10);
        // Mostrar aceleracion
        // mpu.dmpGetQuaternion(&q, fifoBuffer);
        // mpu.dmpGetAccel(&aa, fifoBuffer);
        // mpu.dmpGetGravity(&gravity, &q);
        // mpu.dmpGetLinearAccel(&aaReal, &aa, &gravity);
        // SerialBT.print("areal\t");
        // SerialBT.print(aaReal.x);
        // SerialBT.print("\t");
        // SerialBT.print(aaReal.y);
        // SerialBT.print("\t");
        // SerialBT.println(aaReal.z);
    }
}

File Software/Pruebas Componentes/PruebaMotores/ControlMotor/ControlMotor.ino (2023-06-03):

#include <ESP32Servo.h>
#include "BluetoothSerial.h"

//BLUETOOTH
#if !defined(CONFIG_BT_ENABLED) || !defined(CONFIG_BLUEDROID_ENABLED)
#error Bluetooth is not enabled! Please run `make menuconfig` to and enable it
#endif
//CONSTANTES
#define PIN_MOTOR 25
#define NIVEL_MOTOR_PARADO 0
#define NIVEL_MOTOR_BAJO 1000
#define NIVEL_MOTOR_MEDIOBAJO 1300
#define NIVEL_MOTOR_MEDIOALTO 1600
#define NIVEL_MOTOR_ALTO 1800
#define DELAY_GIRO_MOTORES 5000
//VARIABLES
bool sentido = 0;

enum velocidad{
  MOTOR_PARADO,
  MOTOR_VELOCIDAD_BAJA,
  MOTOR_VELOCIDAD_MEDIABAJA,
  MOTOR_VELOCIDAD_MEDIAALTA,
  MOTOR_VELOCIDAD_ALTA
};
int velocidad = MOTOR_PARADO;
//INSTANCIAMOS OBJETOS
BluetoothSerial SerialBT;
Servo esc;  // Objeto del Servo para controlar el ESC

void setup() {
  Serial.begin(115200);     // Inicializa la comunicación serial a 9600 bps
  esc.attach(PIN_MOTOR);  // Inicializa el servo en el pin correspondiente
  SerialBT.begin("ESP32test"); //Bluetooth device name
  delay(3000);
  SerialBT.println("The device started, now you can pair it with bluetooth!");
}

void loop() {
if(SerialBT.available()){
 switch (velocidad){
    case MOTOR_PARADO:{
      esc.writeMicroseconds(NIVEL_MOTOR_PARADO);
      SerialBT.print("VELOCIDAD: ");
      SerialBT.println(velocidad);
      delay(DELAY_GIRO_MOTORES);
      if (sentido == 1)
      {
        esc.writeMicroseconds(NIVEL_MOTOR_PARADO);
        SerialBT.println("VELOCIDAD FIN ");
        break;
      }
      else velocidad = MOTOR_VELOCIDAD_BAJA;
      break;
      }
    case MOTOR_VELOCIDAD_BAJA:{
      esc.writeMicroseconds(NIVEL_MOTOR_BAJO);
      SerialBT.print("VELOCIDAD: ");
      SerialBT.println(velocidad);
      delay(DELAY_GIRO_MOTORES);
      if (sentido == 1) velocidad = MOTOR_PARADO;
      else velocidad = MOTOR_VELOCIDAD_MEDIABAJA;
      break;
      }
    case MOTOR_VELOCIDAD_MEDIABAJA:{
      esc.writeMicroseconds(NIVEL_MOTOR_MEDIOBAJO);
      SerialBT.print("VELOCIDAD: ");
      SerialBT.println(velocidad);
      delay(DELAY_GIRO_MOTORES);
      if(sentido == 1) velocidad = MOTOR_VELOCIDAD_BAJA;
      else velocidad = MOTOR_VELOCIDAD_MEDIAALTA;
      break;
      }
    case MOTOR_VELOCIDAD_MEDIAALTA:{
      esc.writeMicroseconds(NIVEL_MOTOR_MEDIOALTO);
      SerialBT.print("VELOCIDAD: ");
      SerialBT.println(velocidad);
      delay(DELAY_GIRO_MOTORES);
      if(sentido == 1) velocidad = MOTOR_VELOCIDAD_MEDIABAJA;
      else velocidad = MOTOR_VELOCIDAD_ALTA;
      break;
      }
    case MOTOR_VELOCIDAD_ALTA:{
      esc.writeMicroseconds(NIVEL_MOTOR_ALTO);
      SerialBT.print("VELOCIDAD: ");
      SerialBT.println(velocidad);
      delay(DELAY_GIRO_MOTORES);
      sentido = 1;
      if (sentido == 1) velocidad = MOTOR_VELOCIDAD_MEDIAALTA;
      else velocidad = MOTOR_VELOCIDAD_BAJA;
      break;
      }
  }
}
delay(20);
}

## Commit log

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2023-04-12 empiezo con el sch de la controladora de vuelo
    [PCB-Controladora-Vuelo.kicad_pcb, PCB-Controladora-Vuelo.kicad_sch, PCB-Mando-Radiocontrol-backups.kicad_pcb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]
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2023-04-13 esquematico del pcb del radiocontrol terminado, falta acomoda los componentes y empezar el pcb
    [PCB-Mando-Radiocontrol-backups.kicad_sch]
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2023-04-14 arregle errores de orden y los capacitores queda resolver conexiones si son las correctas , en programador y mcu
    [PCB-Mando-Radiocontrol-backups.kicad_sch]
2023-04-14 huellas asignadas correctamente
    [COM-09032.step, PCB-Mando-Radiocontrol-backups.kicad_pcb, PCB-Mando-Radiocontrol-backups.kicad_sch]
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2023-04-14 Ordene un poco y agregue las librerias de los simbolos y footprints que faltaban
    [PCB-Controladora-Vuelo.kicad_sch, PCB-Mando-Radiocontrol-backups.kicad_pcb, PCB-Mando-Radiocontrol-backups.kicad_sch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]
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2023-04-14 Corregi unos errores
    [PCB-Controladora-Vuelo.kicad_pcb]
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2023-04-15 Cambios en el kicad_sch realice cambios del programador y del capacitor de filtro para el uC ademas rellene el rotulo
    [PCB-Mando-Radiocontrol-backups.kicad_sch]
2023-04-15 cambios en el sch de la Controladora de Vuelo se agrega a la rama los cambios hechos por eze y ademas agregue la alimentacion y ordene, me quedan las conexiones y hacer el symbolo de la controladora 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
    [PCB-Controladora-Vuelo.kicad_sch]
2023-04-17 Agregue conexiones i2c imu y spi transceptor tambien modifique la alimentacion por vin para el uC
    [PCB-Controladora-Vuelo.kicad_sch]
2023-04-17 Avances en el PCB de la controladora de vuelo
    [PCB-Controladora-Vuelo.kicad_pcb, PCB-Controladora-Vuelo.kicad_sch, PCB-Mando-Radiocontrol-backups.kicad_pcb]
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2023-04-18 subo cambios hechos en legui solucione mpu y lugar esp32 mal Footprints
    [PCB-Controladora-Vuelo.kicad_pcb, PCB-Controladora-Vuelo.kicad_sch]
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2023-04-19 muchos cambios leer saque todos los NC y coloque X ya que al poner etiquetas nc reconoce como que debe haber una conexion entre ellos y nqv tambien digamos que hice una buena 1ra parte de pcb, que se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
    [PCB-Controladora-Vuelo.kicad_pcb, PCB-Controladora-Vuelo.kicad_sch]
2023-04-19 Trabaje en el PCB corriegindo ordenes faltaria ver si se pueden agregar pines y corregir que no existan riesgo al momento de planchar o por un corto o abrirse el circuito
    [PCB-Controladora-Vuelo.kicad_pcb, PCB-Controladora-Vuelo.kicad_sch]
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2023-04-21 Errores en el esquematico corregidos
    [PCB-Mando-Radiocontrol-backups.kicad_pcb, PCB-Mando-Radiocontrol-backups.kicad_sch]
2023-04-21 SCH corregido, PCB en proceso a falta de NRF
    [PCB-Mando-Radiocontrol-backups.kicad_pcb, PCB-Mando-Radiocontrol-backups.kicad_sch]
2023-04-22 Hice una mejora con un solo puente de pista 3,3v para transeptor en donde existen riesgos pero mañana trato d mejorar y chequear pines asi se mergea
    [PCB-Controladora-Vuelo.kicad_pcb, PCB-Controladora-Vuelo.kicad_sch]
2023-04-24 MODIFIQUE ESQUEMATICO Y PCB FINALIZADO DIRIA yo falta aprobacion de legui lo deje con 2 puentes para mas seguridad , nuevo puente pin MOSI NRF24L01 Y PLACA LISTA CHEQUEO EL 3D Y VAVVAVVAVA
    [PCB-Controladora-Vuelo.kicad_pcb, PCB-Controladora-Vuelo.kicad_sch]
2023-04-24 SCH Completo, PCB en proceso en un ~80%
    [PCB-Mando-Radiocontrol-backups.kicad_pcb]
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2023-04-24 Cambie capacitores y agregue componentes smd , quedo bien cambie los capacitores electroliticos , queda duda de la huella jst y el posicionamiento de los agujeros de sujecion y ajustar la placa a un 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
    [0603 Capacitor.FCStd, 0603 Resistor.FCStd, 1x4 Female Header.FCStd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]
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2023-04-24 realice modificaciones desde 0 en el PCB a continuar por leandro, es una placa en paralelo a la de gabi
    [100SP3T1B1M2QE.step, PCB-Mando-Radiocontrol-backups.kicad_pcb, PCB-Mando-Radiocontrol-backups.kicad_sch]
2023-04-25 realice la base final de la placa , ordene cosas y cambie pines me falta agregar dos switches y ordenar y corroborar todo
    [PCB-Mando-Radiocontrol-backups.kicad_pcb, PCB-Mando-Radiocontrol-backups.kicad_sch]
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2023-04-26 aplique sugerencias de markow y mias, agregue botones modifique esquematico y pcb
    [PCB-Mando-Radiocontrol.kicad_pcb, PCB-Mando-Radiocontrol.kicad_sch]
2023-04-26 Todos los ejemplos de la IMU probados, solo falta corregir la lectura del eje Z, la cual no logro obtener de forma correcta
    [CalibrarOffSets.ino, LecturaAcelerometro.ino, LecturaBasica.ino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]
2023-04-26 resolviendo problemas de merge
    [BM02B-SRSS-TB.STEP, BM03B-SRSS-TB.STEP, BM04B-SRSS-TB.STEP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]
2023-04-26 hubo un problema en el repositorio, subo la carpeta de la controladora de vuelo terminada nuevamente
    [BM02B-SRSS-TB.STEP, BM03B-SRSS-TB.STEP, BM04B-SRSS-TB.STEP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]
2023-04-27 solucionando problemas
    [BM02B-SRSS-TB.STEP, BM03B-SRSS-TB.STEP, BM04B-SRSS-TB.STEP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]
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2023-04-27 Ordene serigrafia y cambie los capacitores c11 y c12 tht por cmd
    [PCB-Mando-Radiocontrol.kicad_pcb, PCB-Mando-Radiocontrol.kicad_sch]
2023-04-28 Agregue LED y BUZZER , pcb listo para montar
    [PCB-Mando-Radiocontrol.kicad_pcb, PCB-Mando-Radiocontrol.kicad_sch]
2023-04-28 aGREGUE LOGO DE bover group srl en B.CU
    [PCB-Mando-Radiocontrol.kicad_pcb]
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2023-04-28 Agregue el svg de la placa del radiocontrol
    [PCB-Mando-Radiocontrol.kicad_pcb]
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2023-04-30 elimine la carpeta de librerias para ordenar todo mejor
    [100SP3T1B1M2QE.step, BM02B-SRSS-TB.STEP, BM03B-SRSS-TB.STEP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]
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2023-05-01 probe el filtro complementario responde bien, podria mejorar
    [biplane.obj]
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2023-05-27 Funciono correctamente la conexion entre el radiocontrol y el receptor, y agregue un codigo para controlar el motor con el acelerador del control
    [biplane.obj]
2023-05-28 Agrego cambios en el esquematico de la nueva version de la controaldora de vuelo 2.0
    [PCB-Controladora-Vuelo.kicad_sch]
2023-05-28 Cambie pines i2c mpu6050 , hay que probarlos y cambie conexiones de nrf que funcionan, mejore las medidas para el frame
    [PCB-Controladora-Vuelo.kicad_pcb, PCB-Controladora-Vuelo.kicad_sch]
2023-05-28 cambie pines sda y scl para evitar conflictos wifi
    [PCB-Controladora-Vuelo.kicad_pcb, PCB-Controladora-Vuelo.kicad_sch]
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2023-05-30 placa realizada en taller , prueba de pines
    [PCB-Controladora-Vuelo.kicad_pcb, PCB-Controladora-Vuelo.kicad_sch]
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2023-06-02 Modificaciones finales en la V2 del PCB de la FC
    [PCB_Controladora_Vuelo_V2.kicad_pcb, PCB_Controladora_Vuelo_V2.kicad_sch]
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2023-06-04 arregle libreria pid y realice cambios en pruebaspid
    [primerPrueba.ino]
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
